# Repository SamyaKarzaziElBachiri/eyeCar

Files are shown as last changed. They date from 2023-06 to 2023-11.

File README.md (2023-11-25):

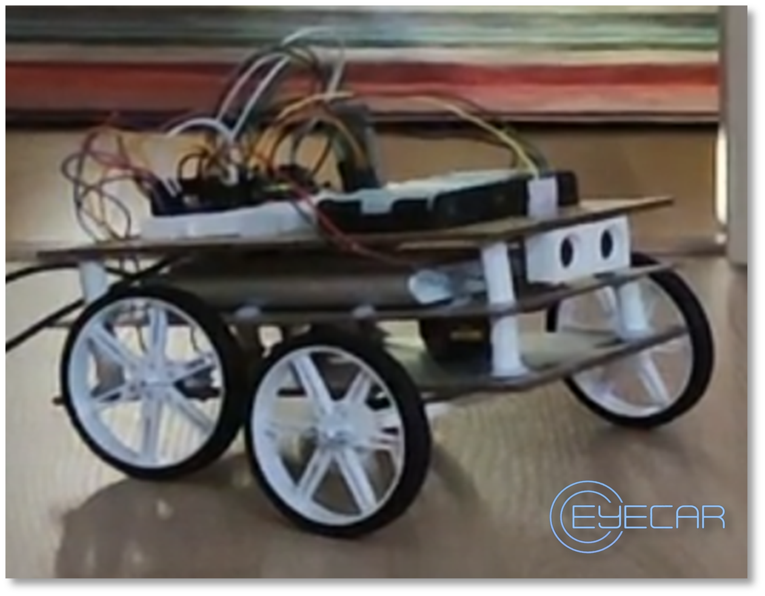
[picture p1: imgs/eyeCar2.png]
header pic


# eyeCar
Project developed for evaluation purposes. 

## Demo
https://youtu.be/9e5DXK_3BVU

## Table of Contents
- [What is this?](#what-is-this)
- [Requirements](#requirements)
- [How to use](#how-to-use)
- [Components](#components)
- [Hardware Scheme](#hardware-scheme)
- [Design software employed](#design-software-employed)
- [Software Architecture](#software-architecture)
- [3D designs](#3d-designs)
- [Contributions](#contributions)
- [Authors](#authors)

## What is this?
This idea of this project is to create a car which can be controlled by the eye of the user. For the safety of the owner it automatically detect obstacles and dangerous environment, acting in response.
Our main goal for this project was to make a system that could ease the use of sanitary wheelchair, making them more autonomous.

## Requirements
- For running the code these are the required languages and libraries:
    * [C (Arduino IDE 2.1.0)](https://docs.arduino.cc/)
        * [servo](https://docs.arduino.cc/tutorials/generic/basic-servo-control)
    * [Python 3.10.x](https://www.python.org/)
        * [numpy](https://numpy.org/doc/)
        * [cmake](https://cmake.org/documentation/)
        * [pySerial](https://pyserial.readthedocs.io/en/latest/)
        * [time](https://docs.python.org/3/library/time.html)
        * [math](https://docs.python.org/3/library/math.html)
        * [dlib](http://dlib.net/python/index.html)
        
## How to use
Currently it is working in basic standards, we made the movement possible through detecting the eye gaze and determine the direction wanted: 
- Right / left: turn
- Front: stay in motion
- Up: start motion
- Close: stop

## Components
 </br>

- Arduino Nano
    - Specs:
        - Weight: 7g
        - PCB size: 18 x 45 mm
        - Arquitecture: AVR
        - Power: 5V
        - Flash Memory: 32 KB
        - SRAM: 2KB
        - Clock speed: 16 MHz
        - Analog IN Pins: 8
        - EEPROM: 1 KB
        - DC Current per I/O Pins: 40 mA (I/O Pins)
        - Input Voltage: 7-12V
        - Digital I/O Pins: 22 (6 of which are PWM)
        - PWM Output: 6
        - Power Consumption: 19 mA

 </br>
- HC-SR04 (Ultrasonic sensors)
    - Specs:
        - Weight: 8.5g
        - Dimension: 45mm x 20mm x 15mm
        - Power Supply: +5V DC
        - Quiescent Current : < 2mA
        - Working Current: 15mA
        - Effectual Angle: < 15°
        - Ranging Distance : 2cm – 400 cm/1″ – 13ft
        - Resolution : 0.3 cm
        - Measuring Angle: 30 degree
        - Trigger Input Pulse width: 10uS TTL pulse
        - Echo Output Signal: TTL pulse proportional to the distance range



- Micro servomotor SG90
    - Specs:
        - Weight: 9g
        - Size: 22.2 x 11.8 x 31 mm
        - Torque: 1.8 kg/cm
        - Speed: 0.1s/60 degrees
        - Power: ~5V
        - Working temperature: 0 ºC - 55 ºC

 

- Motor controller Driver 1a Dual TB6612FNG
    - Specs:
        - Dimensions: 0.8 x 0.8 mm
        - Power supply voltage: VM = 15V max, VCC = 2.7-5.5V
        - Output current: Iout = 1.2A (average) / 3.2A (peak)
        - Standby control to save power
        - CW/CCW/short brake/stop motor control modes
        - Built-in thermal shutdown circuit and low voltage detecting circuit
        - All pins of the TB6612FNG broken out to 0.1" spaced pins
        - Filtering capacitors on both supply lines

 

- Bluetooth module HC-05

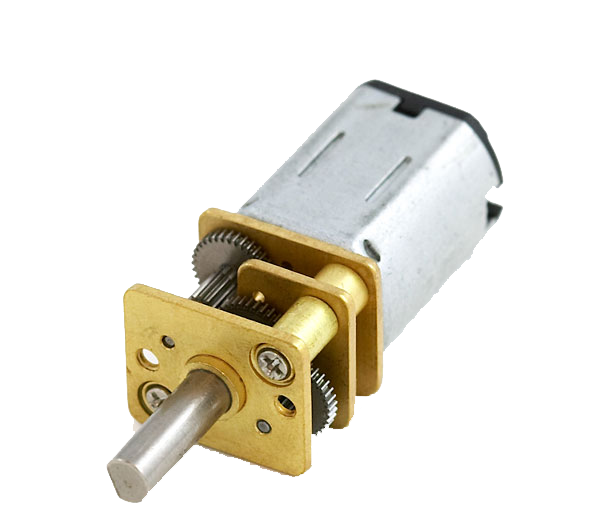
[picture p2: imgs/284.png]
 

- x2 Micro motor LP with gear reducer 10:1
- Protoboard
- x2 pair of wheels
- Battery Poweradd Pilot 2GS 10000mAh
- Battery holder x6 AA

## Hardware scheme
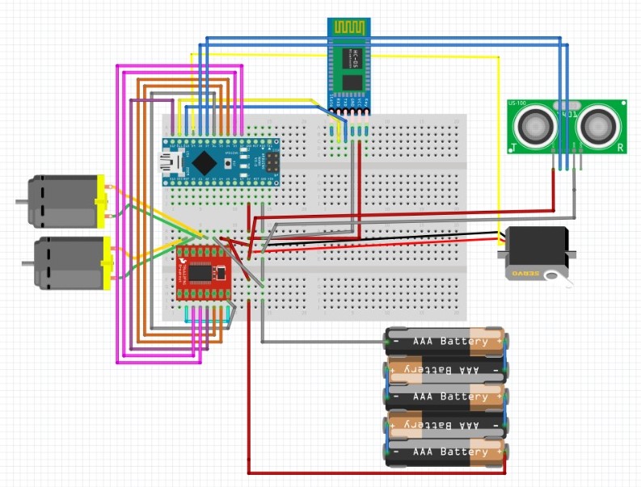
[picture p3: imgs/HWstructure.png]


## Design software employed 
* [Blender 3.5](https://www.blender.org/)
* [UltiMaker Cura 5.3.1](https://ultimaker.com/software/ultimaker-cura/)
* [PrusaSlicer 2.5.2](https://www.prusa3d.com/es/pagina/prusaslicer_424/)

## Software Architecture
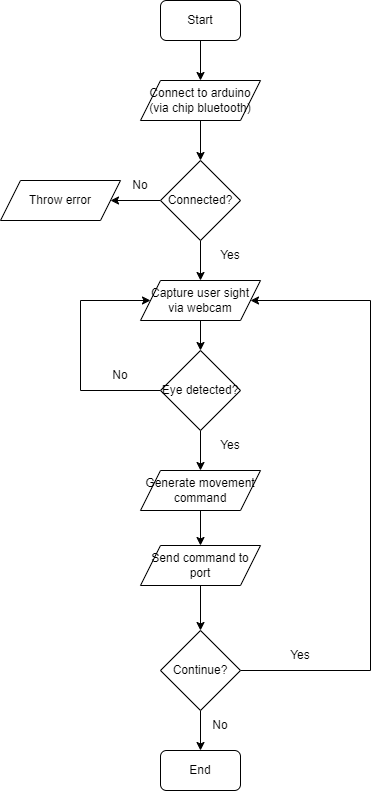
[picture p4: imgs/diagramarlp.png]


## 3D designs
- Ultrasonic sensor cover 

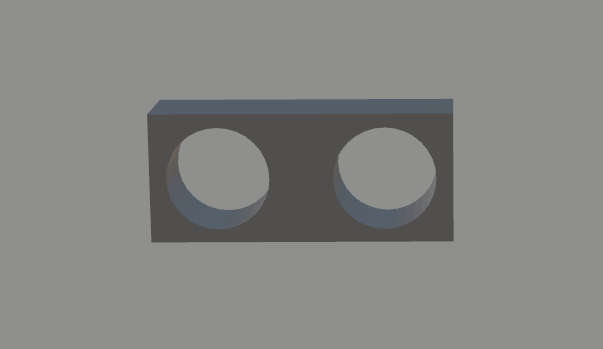
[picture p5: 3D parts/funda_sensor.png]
 </br>

- Wheel bolt bracket

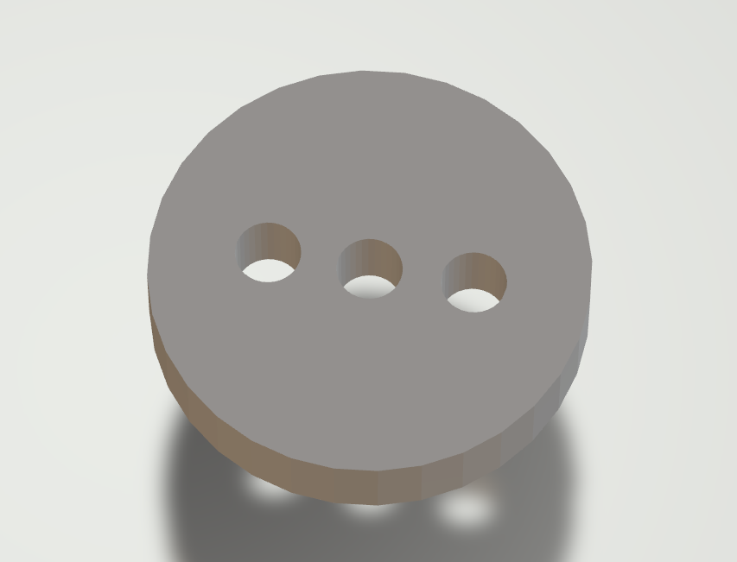
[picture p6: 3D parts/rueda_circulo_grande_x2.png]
 </br>

- Micromotor bracket

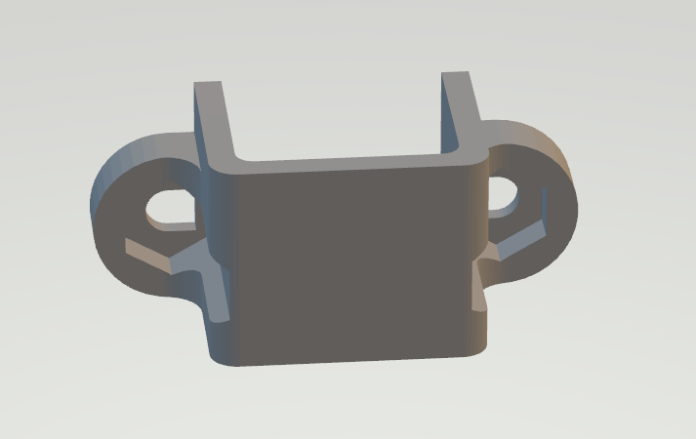
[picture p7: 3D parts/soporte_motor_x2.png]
 </br>

- Layer support

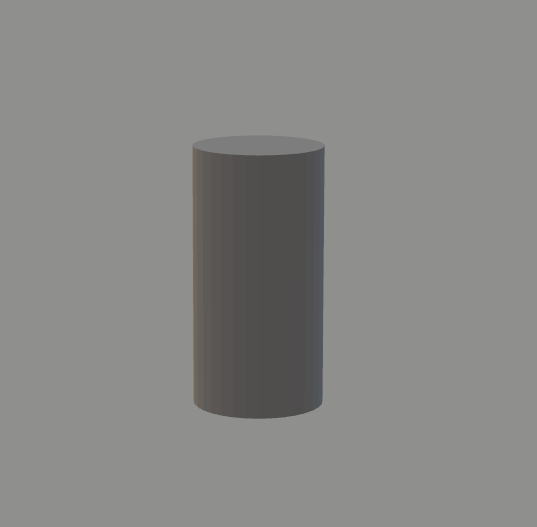
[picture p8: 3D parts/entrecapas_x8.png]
 </br>

- Front wheels axis

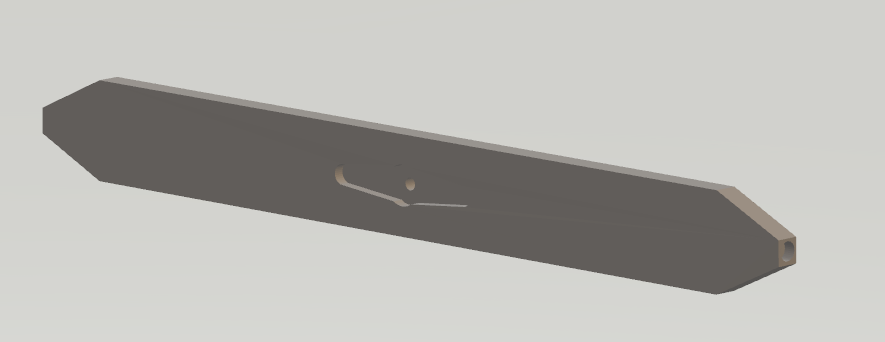
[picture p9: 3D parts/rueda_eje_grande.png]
 </br>

- Layer 1 and 2 - Power supplies and microelectronics

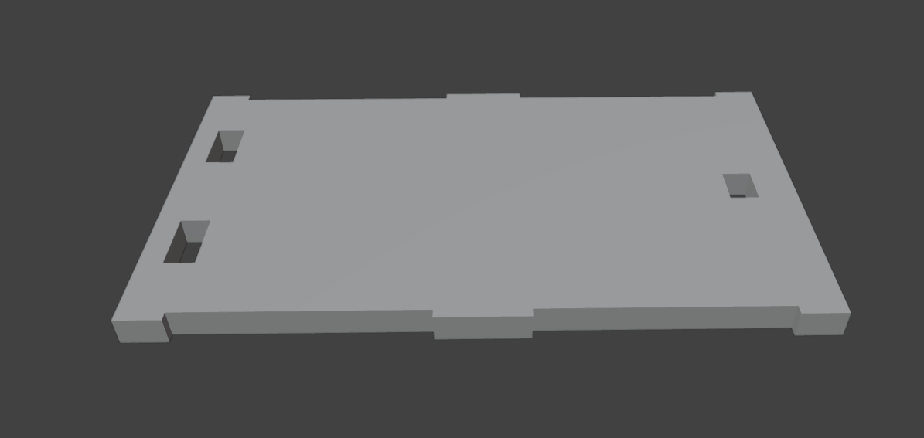
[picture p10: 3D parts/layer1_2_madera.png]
 </br>

- Layer 3 - Wheel support

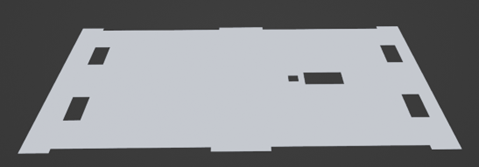
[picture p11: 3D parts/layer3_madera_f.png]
 </br>

## Contributions
Our project aims to provide and contribute to people with reduced mobility and added disabilities to ease their use of wheelchairs or other mobility devices.

We intend to achieve this goal through a comfortable use and a low difficulty curve, through "eye-tracking", since it will adapt to the directions desired by the user without least effort.

This project works testing the aforementioned features using a miniature car model as a prototype, of course with safety in mind, being able to detect obstacles in both directions of traffic, to avoid any type of accident that could affect the user directly.

Taking all these points into account, we can affirm that our project has a large component related to the computer vision field, this being its incentive, although the structuring and designing part of the car must also be included, where we emphasized above all on speed control, user negligence probability and other factors.

We truly believe that our project has excellent potential and a goal of contributing our grain of sand to a needy and important part of society.

## Authors
* Pau Bermúdez Valle - <a href="https://github.com/SrKoko">SrKoko</a> </br>
* Sergio Barranco Aguilar - <a href="https://github.com/Egoris78">Egoris78</a> </br>
* José Francisco Aguilera Oliver - <a href="https://github.com/kaitouser">kaitouser</a> </br>
* Samya Karzazi el Bachiri <a href="https://github.com/SamyaKarzaziElBachiri">SamyaKarzaziElBachiri</a></br>

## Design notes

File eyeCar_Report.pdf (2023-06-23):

RLP – Computer Engineering UAB (Barcelona) 2022-2023

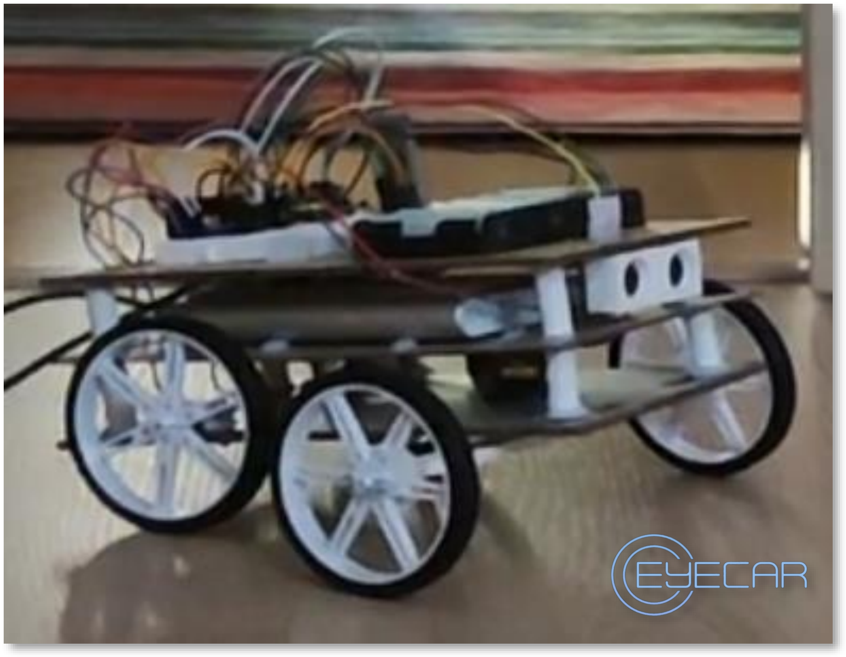
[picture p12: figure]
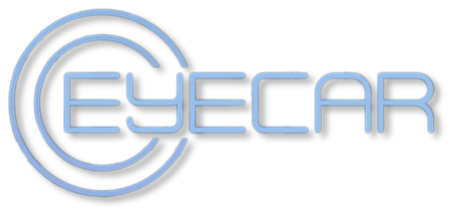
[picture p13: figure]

### A self-driving car controlled by gaze, using Computer

Vision | eye-tracking, | which | also | detects | the
environment and prevents the car from crashing.

PROJECT FINAL SPRINT #6.
DATE: 05 June 2023

Aguilera Oliver, JOSE FRANCISCO Barranco Aguilar, SERGIO
Bermúdez Valle, PAU
Karzazi El Bachiri, SAMYA

eyeCar | 1

# Table of Contents

Project description | 2
Electronic components | 2
Hardware Scheme | 3
Software Architecture | 0
Amazing contributions | 1
Extra components and 3D pieces | 2
Strategy for validation, testing and simulation | 4
Foreseen risks and contingency plan | 4

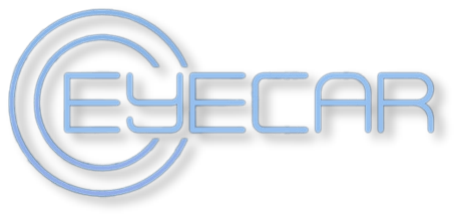
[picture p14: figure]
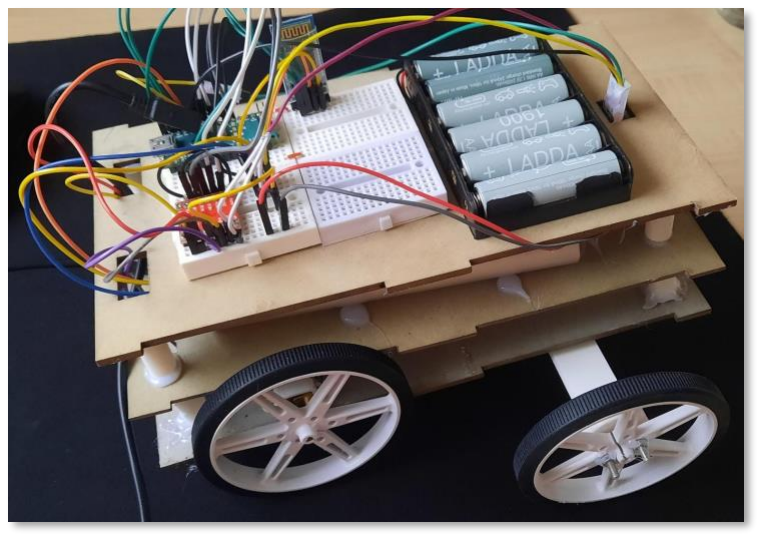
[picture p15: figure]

eyeCar | 2

A self-driving car controlled by gaze, using Computer Vision eye-tracking, which also detects the environment and prevents the car from crashing.

### Project description

eyeCar is a self-driving car controlled
by gaze, using Computer Vision eye-tracking. Create for people that cannot drive.
This car includes a camera that also detects the environment such as the road, objects, people, other cars and prevents it from crashing by stopping and not turning in the direction you have ordered. By doing so we ensure
that | no | accidents | happen | and
everything around us is safe.

### Electronic components

This is the list of the proposed components:

- HC-SR04 (ultrasonic sensors)
- Arduino Nano
- Micro servomotor SG90
- x2 Micromotor with gear reducer 10:1
- Motor controller driver 1a Dual TB6612FNG
- Battery holder 6xAA
- Protoboard
- HC-05 Bluetooth

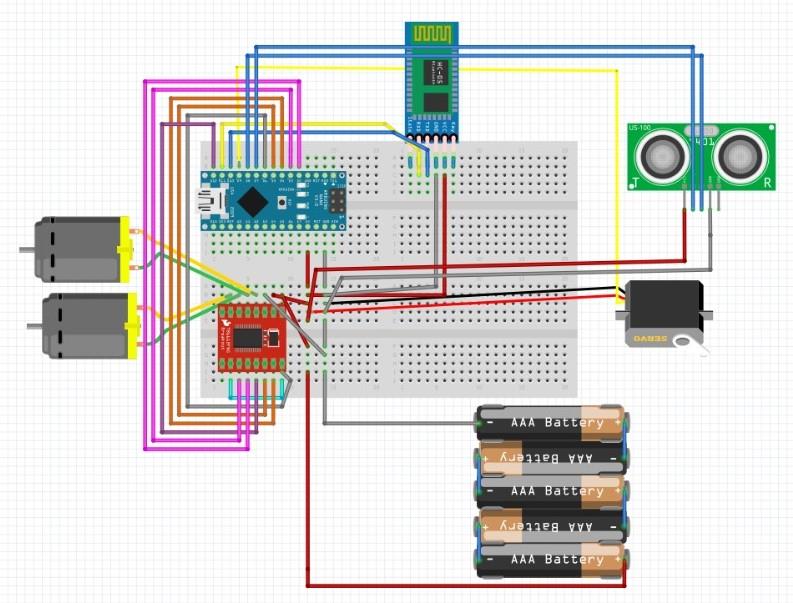
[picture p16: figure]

eyeCar | 3

### Hardware Scheme

Arduino D12 --> STBY controller

Arduino D11 --> RDX HC-05

Arduino D10 --> TDX HC-05

Arduino D9 --> Servo

Arduino D8--> Echo Sensor

Arduino D7--> Trigger Sensor

Arduino D6--> Power Motor 1 & 2

Arduino D5--> Ain1 controller

Arduino D4-> Ain2 controller

Arduino D3--> Bin1 controller

Arduino D2--> Bin2 controller

Arduino 5v --> VCC controller & VCC HC-05 & VCC Servo & VCC Sensor

Arduino GND--> GND controller & GND HC-05 & GND Servo & GND Sensor

RLP – Computer Engineering UAB (Barcelona) 2022-2023

### Software Architecture

main():

Responsible for executing all the functions needed to action our eyeCar.

lectorPupila():
This function uses the laptop's camera to detect the
position of the pupil to estimate its movement. So, this function updates the movement values. Depending on the gaze direction, it will modify the speed or braking direction value.
- Look to the left: turn left.
- Look to the right: turn right.
- Look up: accelerate.
- Look down: brake.
- Other actions not yet decided.

To make this possible we utilize a pretrained model that detects and crops the face region of the person in front of the camera. Then we split this region in two, to get the right and left sides of the face. We use another pretrained model that crops the eye region on both sides, giving us a real time frame of our left and right eye. We could use the two eyes to estimate the pupil position, but in our case, we only used the right eye for
the further calculations.

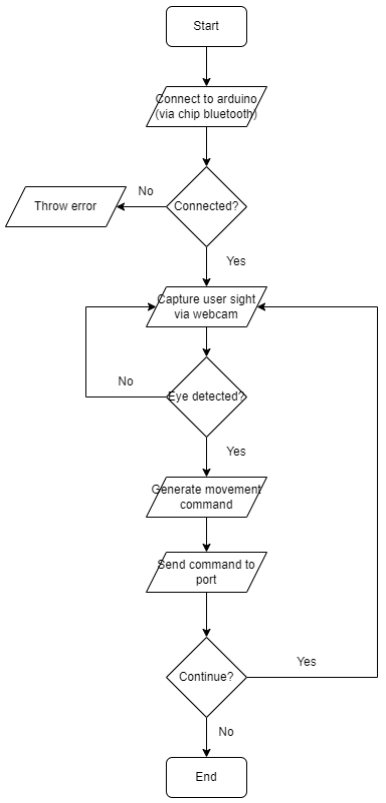
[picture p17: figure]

Next step is to convert the eye frame to grey scale, apply some noise reducing filters and apply a thresholder to binarize the pupil from the rest of the eye. Once we have the pupil binarized we extract the centroids, which represent the centres of the main binarized sections of the image. The centroid of the biggest section will be, theoretically, the centre of our pupil.

eyeCar | 1

We now do a process of synchronization, where we ask the user to look at each direction and press enter. With this process we save the coordinates of the centroid detected on each direction so that, thereafter, we can predict where the user is looking comparing the actual coordinates with the coordinates of the sync process and giving as a result the direction closest to.

movement():
This function is responsible for giving instructions to the two motors and servo, making the car move as a result. We send the commands as numbers to our robot via a port of our Wi-Fi chip.
The directions, speed and motor braking commands will be given by the readerPupila() function, with the received values we will update the direction using the rotation of the servomotor or increasing and decreasing the speed of the motors at will.

### Amazing contributions

Our project aims to provide and contribute to people with reduced mobility and added disabilities to ease their use of wheelchairs or other mobility devices.

We intend to achieve this goal through a comfortable use and a low difficulty curve, through "eye-tracking", since it will adapt to the directions desired by the user without least effort.

This project works testing the features using a miniature car model as a prototype, of course with safety in mind, being able to detect obstacles in both directions of traffic, to avoid any type of accident that could affect the user directly.

Taking all these points into account, we can affirm that our project has a large component related to the computer vision field, this being its incentive, although the structuring and designing part of the car must also be included, where we emphasized above all on speed control, user negligence probability and other factors.

We truly believe that our project has excellent potential and a goal of contributing our grain of sand to a needy and important part of society.

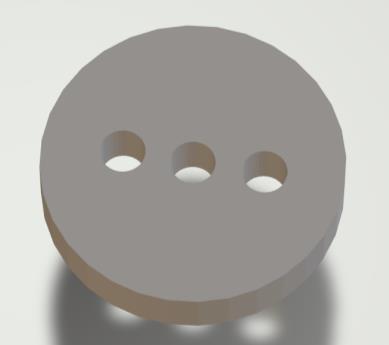
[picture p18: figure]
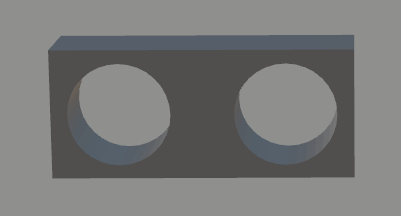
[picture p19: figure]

eyeCar | 2

### Extra components and 3D pieces

- Ultrasonic sensor cover
- Wheel bolt bracket
- Micromotor bracket
- Layer support
- Front wheels axis
- Layer 1 and 2 – Power supplies and microelectronics
- Layer 3 – Wheel support

In the annex we have included the sketch of what contains each layer visually.

Ultrasonic sensor cover: used to cover the ultrasonic sensor and stick it in the upper layer.

Wheel bolt bracket: used to hold the bolts of the wheels and attach them to the wheels’ axis.

Micromotor bracket: designed to hold the micromotors and attach them to the base.

Layer support: to create a separation between layers.

Front wheels axis: used to turn the front wheels to the right or left using only one servomotor.

Layer 1 and 2 – Power supplies and microelectronics support: used to hold the protoboard, every cable, Arduino, the ultrasonic sensor, the portable battery, and the batteries.

Layer 3 – Wheel support: used to screw the motors and servomotor to hold the wheels.

Fig. 1 - Ultrasonic sensor cover Fig. 2 – Wheel bolt bracket

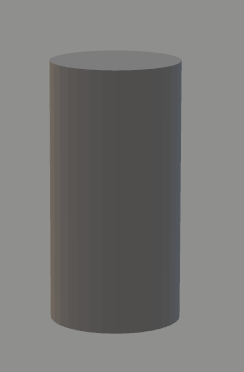
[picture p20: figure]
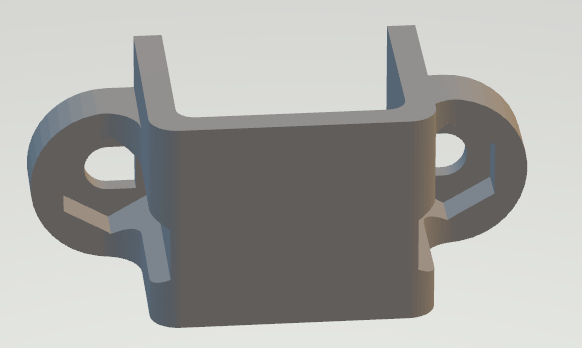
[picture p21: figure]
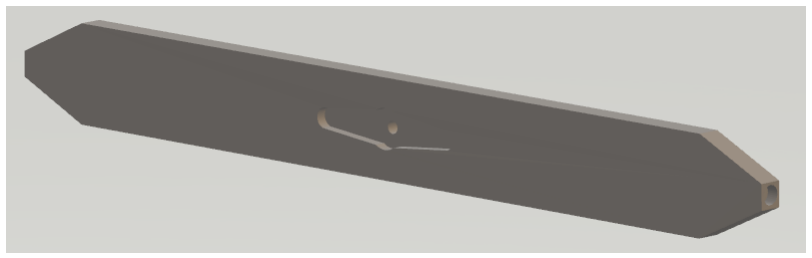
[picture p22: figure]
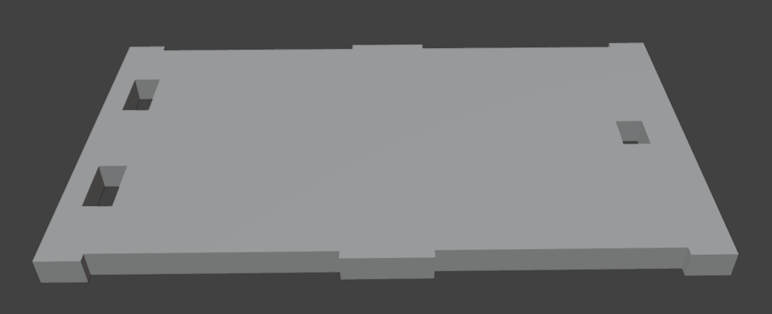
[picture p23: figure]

eyeCar | 3

Fig. 3 – Micromotor bracket Fig. 4 – Layer support

Fig. 5 – Front wheels axis

Fig. 6 - Layer 1 and 2 – Power supplies and microelectronics

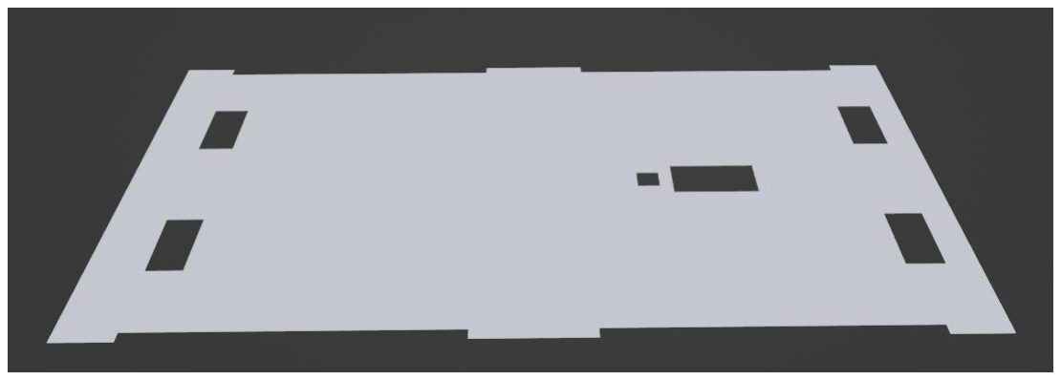
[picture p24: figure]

eyeCar | 4

Fig. 7 - Layer 3 – Wheel support

### Strategy for validation, testing and simulation

Our strategy for validation is to evaluate the car in a car circuit mounted by us and see if it follows our orders of changing the route. We also want to test if it detects objects by adding “people”, objects, and other cars in the circuit. This strategy of validation will be done with a challenging simulation and a simple real circuit.

### Foreseen risks and contingency plan

Risk # | Description | Probability (High/Medium/Low) | Impact (High/Medium/Low) | Contingency plan
Collision | If our robot moves too fast or our remote-control system fails, there may be a risk of collision with other objects or people. | Medium | Medium | Implement speed control systems and proximity sensors that detect obstacles and stop the robot before a possible impact. As well as stopping the robot immediately if the connection with the remote-control system by eye tracking is lost.

eyeCar | 5
Internal damage | If the robot is handled incorrectly or receives an external shock, the electronic components could be damaged. | Medium | Medium | Design and print a 3D housing that offers some protection to all components of the robot. In addition, the housing should be as aerodynamic as possible to ensure a good displacement of the robot.
Burn | If our robot overheats or there is a short circuit, there may be a risk of the robot catching fire. | Medium | High | Add temperature sensors that stop robot operation if certain temperatures are exceeded. (Not implemented on final model)

eyeCar | 6

# References

This project is inspired by the following Internet projects:

[1] https://projecthub.arduino.cc/aadhuniklabs/3eb4a951-a51e-4999-82ab-94a6128e91c4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 (https://projecthub.arduino.cc/aadhuniklabs/3eb4a951-a51e-4999-82ab-94a6128e91c4?offset=6)
[2] https://www.ijert.org/research/hand-gesture-control-car-IJERTCONV8IS05066.pdf
[3] https://visnav.in/ijabs/wp-content/uploads/sites/11/2021/12/Wireless-Robotic-car-control-through-human-interface-using-eye-movement.pdf

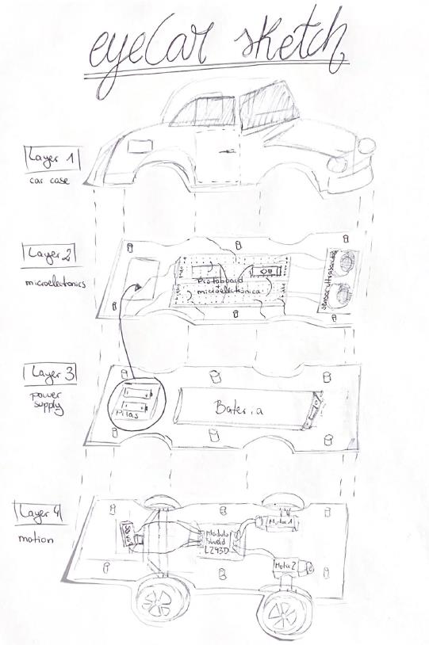
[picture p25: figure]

eyeCar | 7

# ANNEX

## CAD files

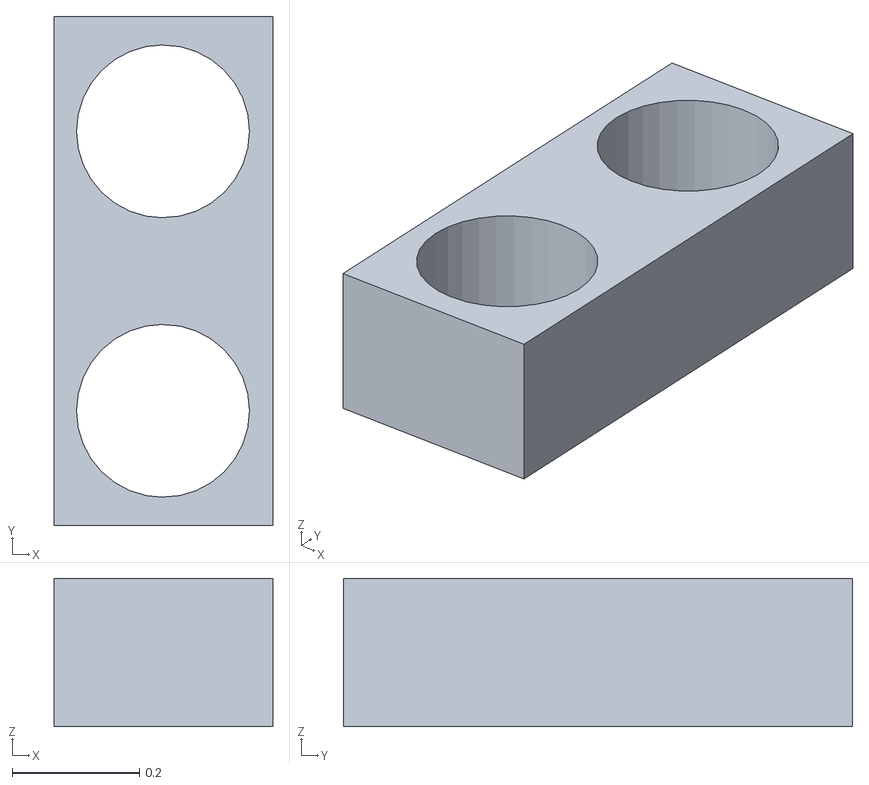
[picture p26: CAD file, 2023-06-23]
3D parts/funda_sensor.stl
0.344 x 0.8 x 0.233

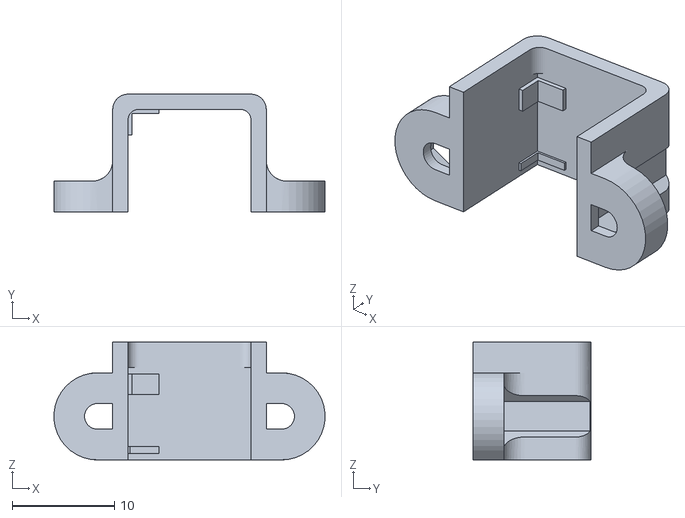
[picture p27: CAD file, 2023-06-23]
3D parts/soporte_motor_x2.stl
26.5 x 11.5 x 11.5

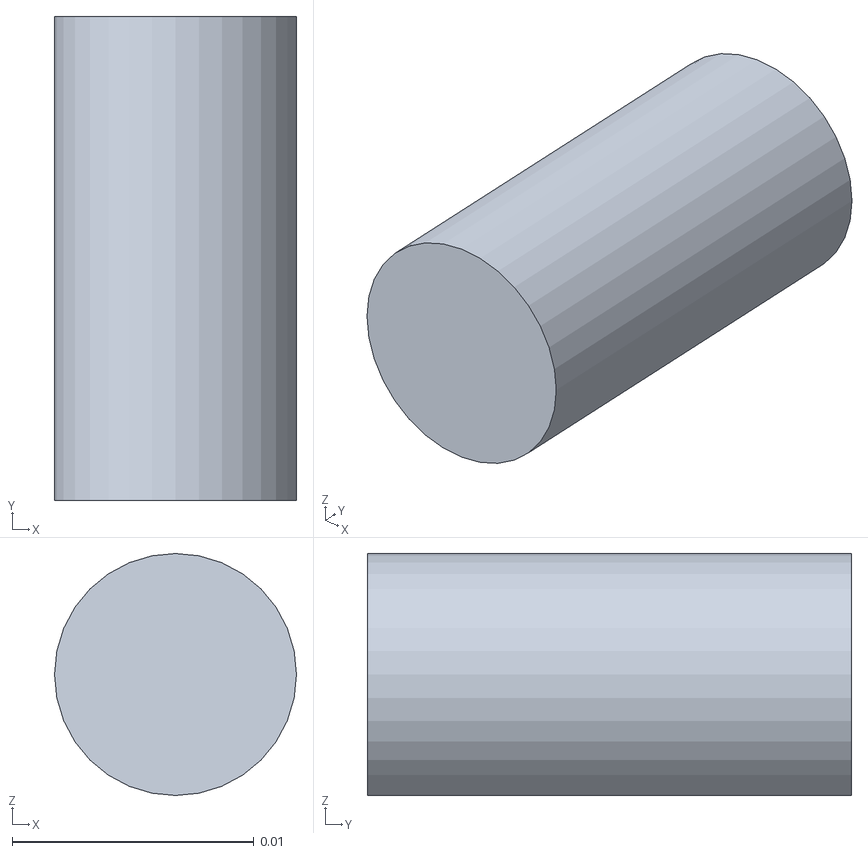
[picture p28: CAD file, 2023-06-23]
3D parts/entrecapas_x2.stl
0.01 x 0.02 x 0.01

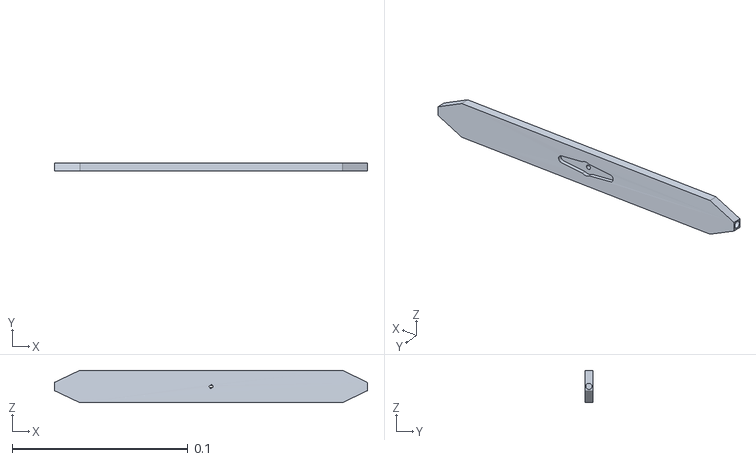
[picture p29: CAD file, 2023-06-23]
3D parts/rueda_eje_grande.stl
0.178 x 0.00462 x 0.0185

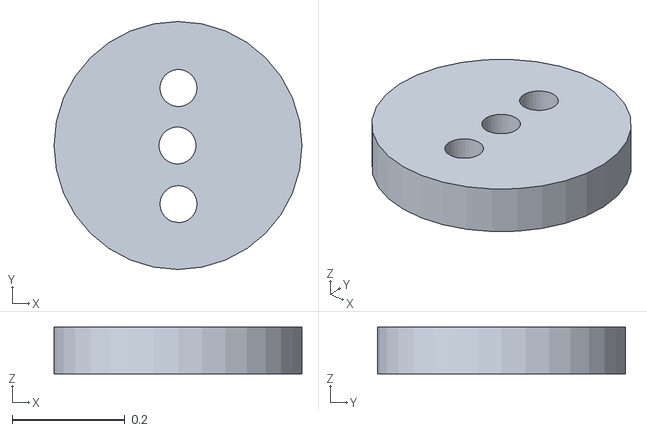
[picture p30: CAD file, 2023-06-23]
3D parts/rueda_circulo_grande_x2.stl
0.441 x 0.441 x 0.0833

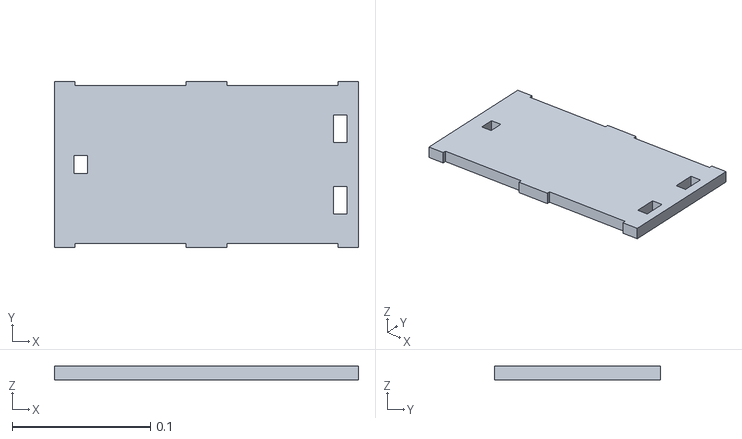
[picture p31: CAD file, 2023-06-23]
3D parts/layer1_2_madera.stl
0.22 x 0.12 x 0.01

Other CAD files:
3D parts/layer3_madera.stl

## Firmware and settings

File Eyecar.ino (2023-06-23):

// C++ code
//
#include<Servo.h>
#include<SoftwareSerial.h>
#include "NewPing.h"
//Pines del sensor
#define onOffMotor 12
#define TRIGGER_PIN 7
#define ECHO_PIN 8
#define A1 6
#define A2 5
#define B1 3
#define B2 2
#define speedPin 4
#define speed 170
//Centimetros
#define MAX_DISTANCE 500
SoftwareSerial BtSerial(10,11);
Servo motor;
int direcction = 0;
bool stop=false;
int actualPos=45;
NewPing sonar(TRIGGER_PIN,ECHO_PIN,MAX_DISTANCE);
void setup()
{
  motor.attach(9);
  Serial.begin(9600);
  BtSerial.begin(9600);
  motor.write(45);
  pinMode(A1,OUTPUT);
  pinMode(A2,OUTPUT);
  pinMode(B1,OUTPUT);
  pinMode(B2,OUTPUT);
  pinMode(speedPin,OUTPUT);
  pinMode(onOffMotor,OUTPUT);
  digitalWrite(A1, LOW);
  digitalWrite(A2, LOW);
  digitalWrite(B1, LOW);
  digitalWrite(B2, LOW);
  analogWrite(speedPin,speed);
  digitalWrite(onOffMotor,HIGH);
}

int girarDerecha(){
  if(actualPos < 60){
    actualPos += 5;
    motor.write(actualPos);
    delay(50);
  }
  return actualPos;
}
int girarIzquierda(){
  if(actualPos > 30){
    actualPos -= 5;
    motor.write(actualPos);
    delay(50);
  }
  return actualPos;
}
int centrar(){
  while(actualPos!=45){
    if(actualPos>45){
      actualPos-= 5;
      motor.write(actualPos);
      delay(150);
    }
    else{
      actualPos+= 5;
      motor.write(actualPos);
      delay(150);
    }
  }
  return actualPos;
}

void forward() {          //function of forward 
  analogWrite(A1, 255);
  analogWrite(A2, 0);
  analogWrite(B1, 255);
  analogWrite(B2, 0);
}

void backward() {         //function of backward
  analogWrite(A1, 0);
  analogWrite(A2, 210);
  analogWrite(B1, 0);
  analogWrite(B2, 210);
}

void Stop() {              //function of stop
  digitalWrite(A1, LOW);
  digitalWrite(A2, LOW);
  digitalWrite(B1, LOW);
  digitalWrite(B2, LOW);
}

void test(){
  motor.write(45);
  actualPos=45;
  delay(3000);
  motor.write(0);
  delay(3000);
  motor.write(90);
}


void testMotor(){
  forward();
  Serial.println("forward");
  delay(3000);
  //backward();
  //Serial.println("backward");
  //delay(3000);
  Stop();
  Serial.println("Stop");
  delay(3000);
}

void loop()
{
  //motor.write(45);
  if(BtSerial.available()){
    char value = BtSerial.read();
    Serial.write(value);
    Serial.write((int)value-48);
    switch((int)value-48){
      case 0:actualPos= centrar();
        break;
      case 1: actualPos=girarIzquierda();
        break;
      case 2: actualPos=girarDerecha();
        break;
      case 3: forward();
        break;
      case 4 : Stop();
        break;
      case 5: stop=true;
        Serial.write("Stoping");
        break;
    }
  }
  //test();
  //testMotor();
  if(sonar.ping_cm() < 20 && sonar.ping_cm() != 0 ){
    digitalWrite(onOffMotor,LOW);
    Serial.print("Distance = ");
    Serial.print(sonar.ping_cm());
    Serial.println(" cm");
  }
  else{
    digitalWrite(onOffMotor,HIGH);
  }
  while(stop){}

}

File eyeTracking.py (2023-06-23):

# -*- coding: utf-8 -*-
"""
Created on Wed May  1 00:06:08 2023

@author: Srkokiko
"""

#Cargamos librerias
import cv2
import dlib
import math
import time
import serial
import numpy as np


serialPort = None
updateTime = 0.75

#Cargamos los modelos pre entrenados de detección de caras y de ojos
detector_caras = dlib.get_frontal_face_detector()
detector_ojos = dlib.shape_predictor("./preTrainedModels/shape_predictor_68_face_landmarks.dat")

#Capturamos el vídeo de la webcam
video = cv2.VideoCapture(0) #0 es dispositivo de vídeo default; la webcam si tenemos

sightDirection = "none"
output = "none"

coordinates = [] #Para guardar las coordenadas de sincronización
status = 0 #Para saber en que estado de sincronización estamos, -1 si ya hemos terminado la sync
print("PROCESO DE SINCRONIZACIÓN")
print("Mire hacia delante y presione enter")

while True: #Mientras no le demos al esc nuestro programa seguirá activo
      
    if (sightDirection == "none"):
        start = time.time()
            
    #Leemos el vídeo frame por frame en tiempo real
    ret, frame = video.read()
    
    #Convertimos el frame a escala de grises
    frameGris = cv2.cvtColor(frame, cv2.COLOR_BGR2GRAY)

    #Identificamos los rostros en el frame
    caras = detector_caras(frameGris)

    if len(caras) > 0: #Si se ha detectado almenos una cara
    
        #Identificamos los ojos dentro de las caras
        ojos = detector_ojos(frameGris, caras[0])
        
        #Extraemos las coordenadas de cada ojo
        zoom = 10 #A mayor valor menos zoom
        ojo_izquierdo = (ojos.part(36).x - zoom, ojos.part(36).y - zoom, ojos.part(39).x - ojos.part(36).x + zoom*2, ojos.part(41).y - ojos.part(37).y + zoom*2)
        ojo_derecho = (ojos.part(42).x - zoom, ojos.part(42).y - zoom, ojos.part(45).x - ojos.part(42).x + zoom*2, ojos.part(47).y - ojos.part(43).y + zoom*2)
        
        #Recortamos la sección del frame donde se encuentran los ojos
        frame_ojo_izquierdo = frame[ojo_izquierdo[1]:ojo_izquierdo[1]+ojo_izquierdo[3], ojo_izquierdo[0]:ojo_izquierdo[0]+ojo_izquierdo[2]]
        frame_ojo_derecho = frame[ojo_derecho[1]:ojo_derecho[1]+ojo_derecho[3], ojo_derecho[0]:ojo_derecho[0]+ojo_derecho[2]]
        
        #Convertimos el frame del ojo derecho a escala de grises
        frame_ojo_derecho_gray = cv2.cvtColor(frame_ojo_derecho, cv2.COLOR_BGR2GRAY)
        
        #Reducimos ruido con un filtro gaussiano
        frame_ojo_derecho_blur = cv2.GaussianBlur(frame_ojo_derecho_gray, (5,5), 0)
        
        #Binarizamos la imagen para resaltar la pupila
        ret, frame_ojo_derecho_binarized = cv2.threshold(frame_ojo_derecho_blur, 120, 255, cv2.THRESH_BINARY_INV)
        
        if np.max(frame_ojo_derecho_binarized) == 255: #Si se ha detectado algun componente
            #Encontramos los diferentes componentes en el frame
            num_labels, labels, stats, centroids = cv2.connectedComponentsWithStats(frame_ojo_derecho_binarized)
        
            #Cojemos el indice del componente conectado más grande, que deberia ser la pupila
            largest_label = 1 + np.argmax(stats[1:, cv2.CC_STAT_AREA])
            
            #Obtenemos el ROI de la pupila
            x, y, w, h, area = stats[largest_label]
            coord = (x,y)
            roi = frame_ojo_derecho[y:y+h, x:x+w]
            
            #Dibujamos un circulo alrededor de la pupila
            cv2.circle(frame_ojo_derecho, (int(x+0.5*w), int(y+0.5*h)), int(0.5*np.sqrt(area/np.pi)), (0, 255, 0), 2)
            
            if (status == -1): #Si ya hemos hecho la sincronización
            
                #Inicializamos la minima distancia y la coordenada más próxima
                min_distance = math.inf
                closest_coordinate = None
                
                for it,c in enumerate(coordinates): #Iteramos entre las coordenadas
                    distance = math.sqrt((coord[0]-c[0])**2 + (coord[1]-c[1])**2) #Calculamos la distancia euclidea
                    
                    #Miramos si la coordenada és la mínima hasta el momento
                    if distance < min_distance:
                        min_distance = distance
                        closest_coordinate = c
                        closest_coordinates_index = it
                        
                #Según la coordenada más próxima damos un resultado
                if (closest_coordinates_index == 0):
                    #print("La dirección de la mirada es hacia delante")
                    sightDirection = "front"
                elif (closest_coordinates_index == 1):
                    #print("La dirección de la mirada es hacia la derecha")
                    sightDirection = "right"
                elif (closest_coordinates_index == 2):
                    #print("La dirección de la mirada es hacia la izquierda")
                    sightDirection = "left"
                elif (closest_coordinates_index == 3):
                    #print("La dirección de la mirada es hacia arriba")
                    sightDirection = "up"
                elif (closest_coordinates_index == 4):
                    #print("La dirección de la mirada es hacia abajo")
                    sightDirection = "down"
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
